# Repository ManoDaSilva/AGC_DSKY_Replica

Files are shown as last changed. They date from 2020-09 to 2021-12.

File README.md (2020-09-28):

# AGC_DSKY_Replica
Mechanically accurate Apollo DSKY replica.

This project is based off the 3D models I re-created from the original MIT Instrumentation Labs drawings (those models can be found on [VirtualAGC's GitHub](https://github.com/virtualagc/virtualagc/tree/mechanical/3D-models)). 
In order to 3D print them, I slightly modified them (widened some holes for brass inserts, keyboard, etc).

A Raspberry Pi running VirtualAGC is doing the grunt work, the display is a simple LCD and the status lights are LEDs. 

More on the [Hackaday.io project page](https://hackaday.io/project/174524).

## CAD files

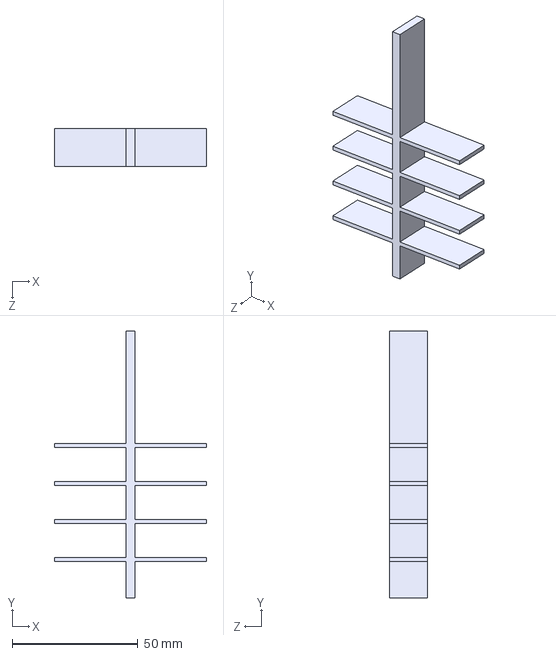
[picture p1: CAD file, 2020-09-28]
3D Models/Led_splitter.stp
60.5 x 106.1 x 15.0 mm

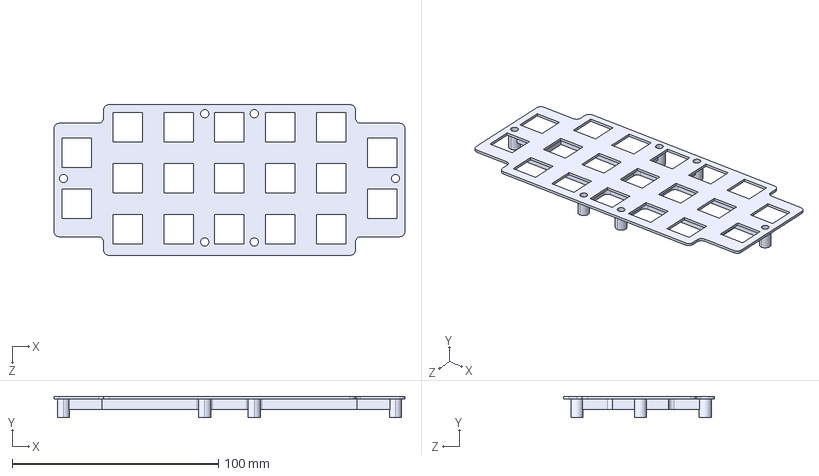
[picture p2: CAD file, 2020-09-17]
3D Models/Keyboard Mk1/cherrysupport-nopcb.stp
170.0 x 10.3 x 73.0 mm

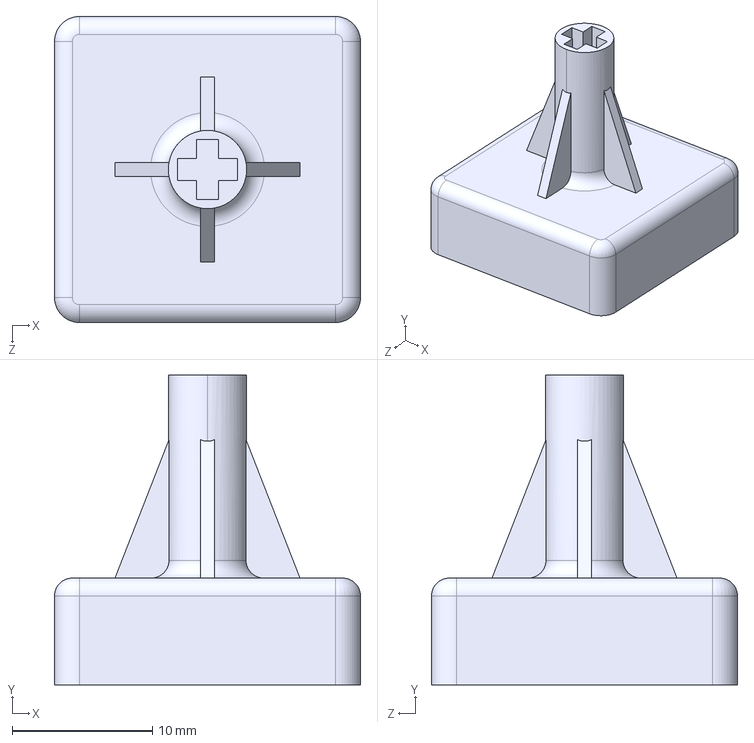
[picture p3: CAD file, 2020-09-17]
3D Models/Keyboard Mk1/keyboard case.stp
21.8 x 22.1 x 21.8 mm

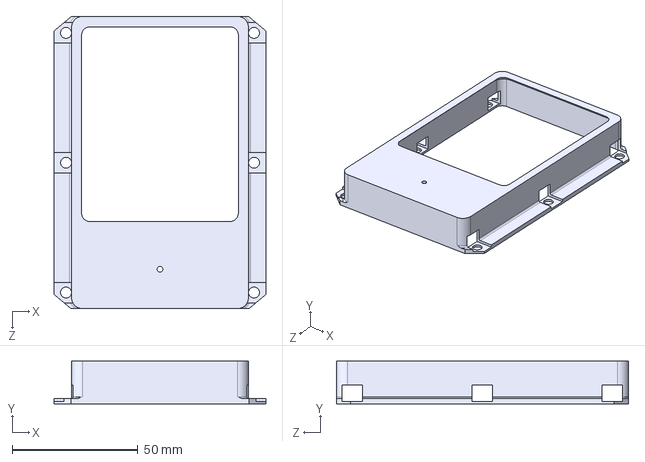
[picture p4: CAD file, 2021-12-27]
3D Models/2004699A-000.STEP
84.2 x 17.0 x 116.1 mm

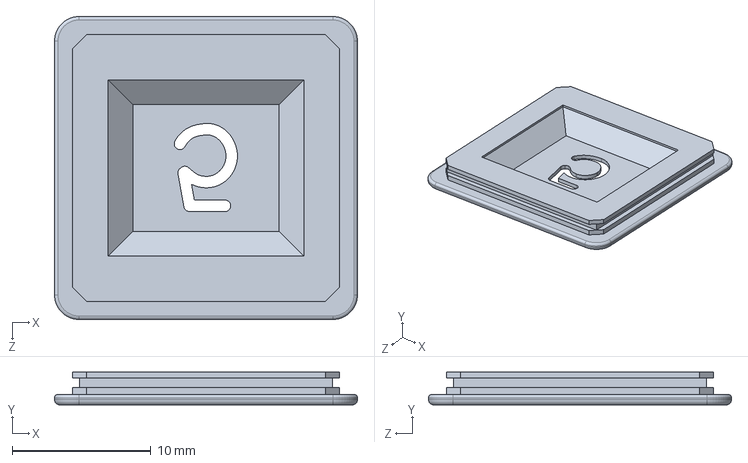
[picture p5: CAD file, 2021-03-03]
3D Models/Keyboard Mk1/1005022-015.STEP
21.8 x 2.36 x 21.8 mm

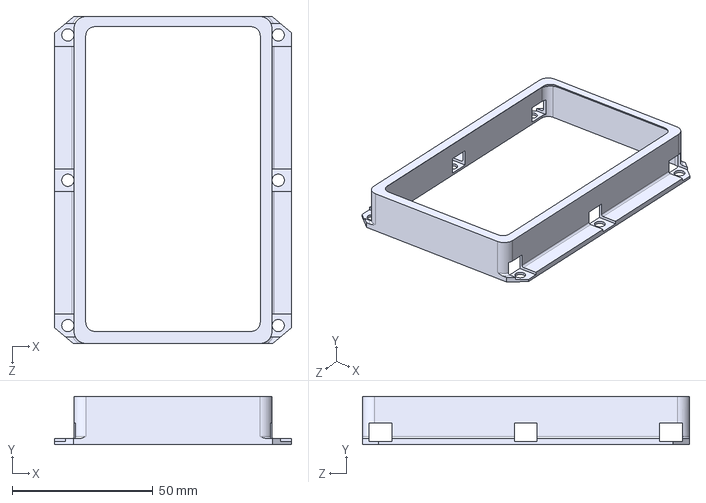
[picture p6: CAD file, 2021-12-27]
3D Models/2004699A-001.STEP
84.2 x 17.0 x 116.1 mm

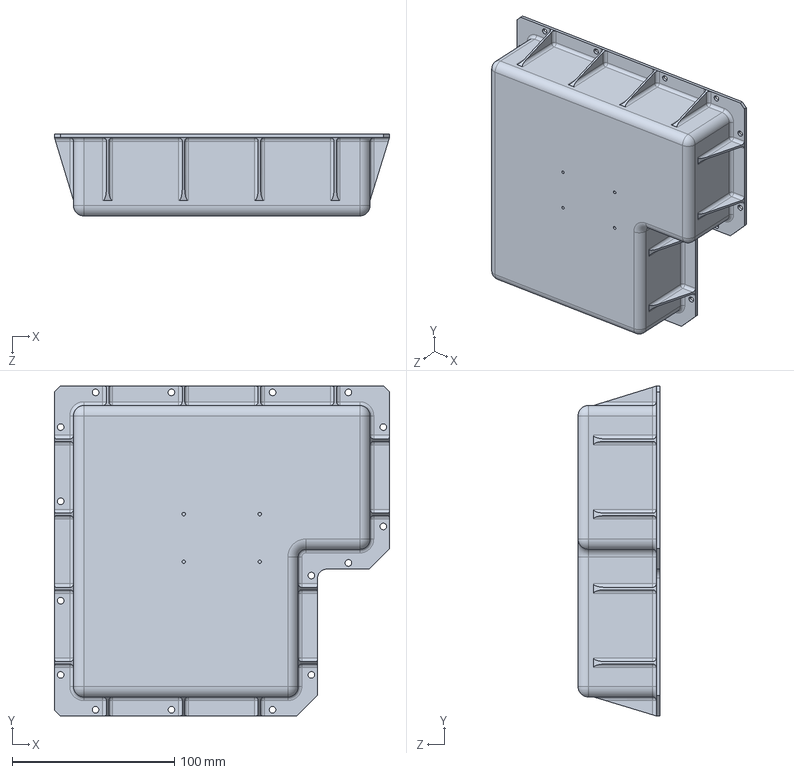
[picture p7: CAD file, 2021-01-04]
3D Models/2004900A.stp
206.3 x 203.2 x 50.4 mm

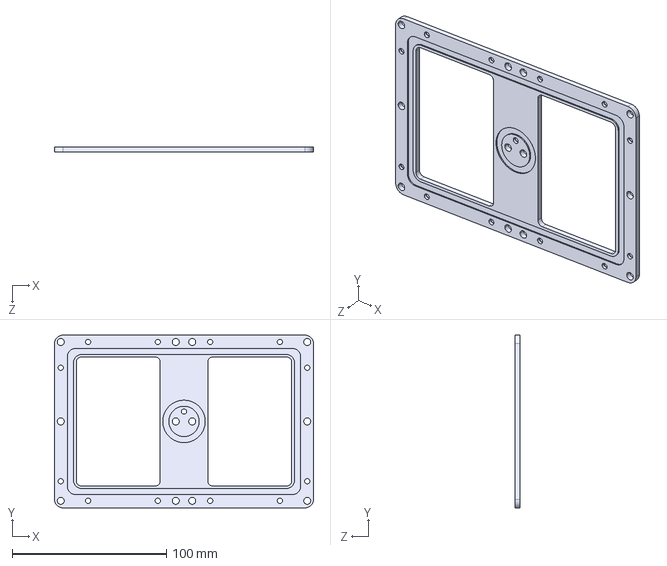
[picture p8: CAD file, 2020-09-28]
3D Models/1006315A.stp
168.1 x 112.1 x 3.18 mm

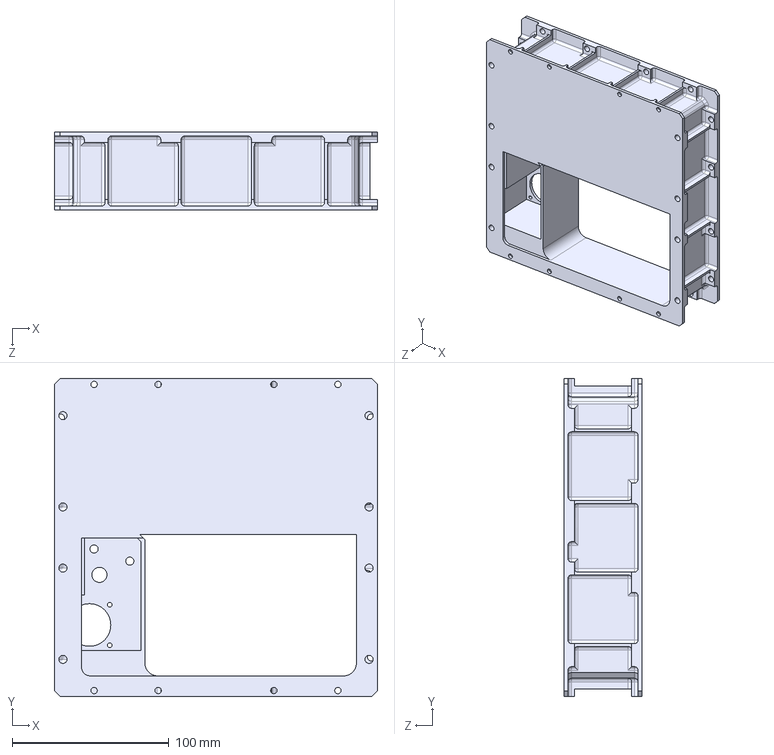
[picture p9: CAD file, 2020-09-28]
3D Models/2004705A_modfor3Dprint.stp
206.3 x 203.2 x 49.8 mm

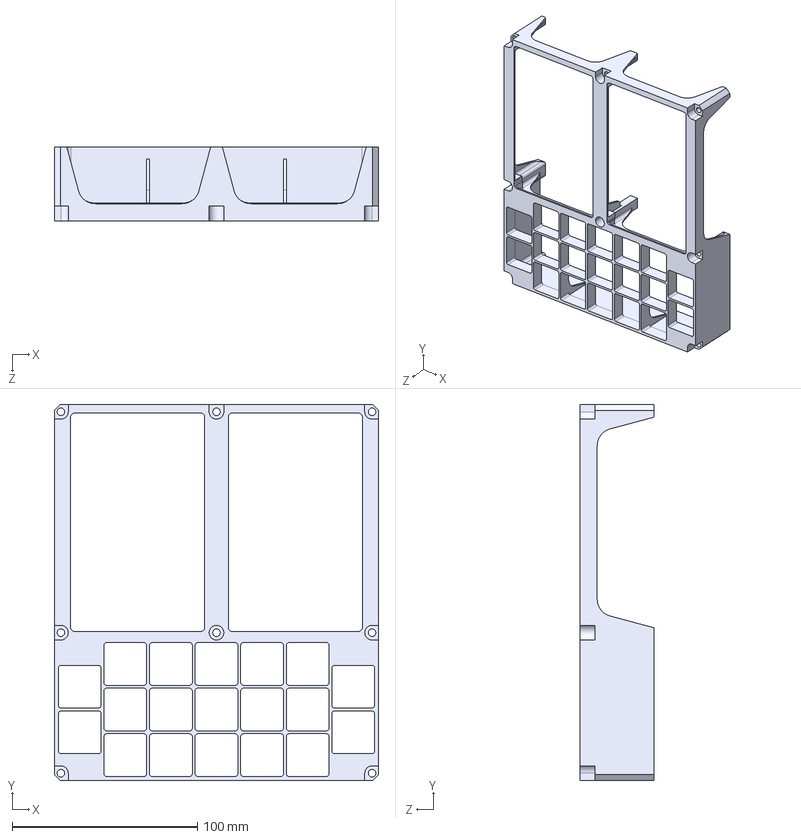
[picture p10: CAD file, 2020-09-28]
3D Models/2004739A-021-ModFor3DPrint.stp
175.3 x 203.2 x 39.9 mm

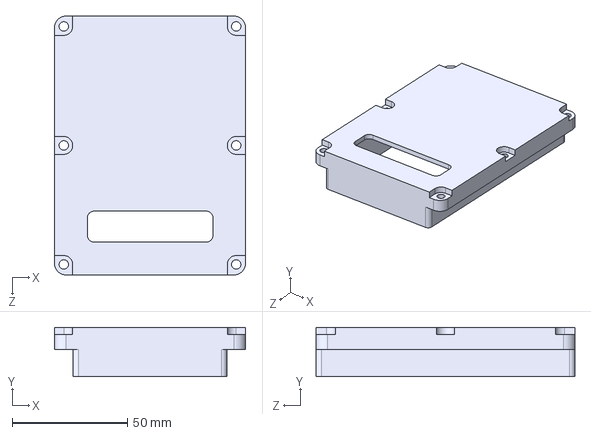
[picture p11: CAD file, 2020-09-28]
3D Models/1006387D-ModFor3DPrint.stp
82.8 x 21.3 x 112.2 mm

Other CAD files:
3D Models/Keyboard Mk1/1005022-007.STEP
3D Models/Keyboard Mk1/1005022-003.STEP
3D Models/Keyboard Mk1/1005022-018.STEP
3D Models/Keyboard Mk1/1005022-013.STEP
3D Models/Keyboard Mk1/1005022-008.STEP
3D Models/Keyboard Mk1/1005022-001.STEP
3D Models/Keyboard Mk1/1005022-006.STEP
3D Models/1006315G-ModFor3DPrint.stp
3D Models/1006315GCover-ModFor3DPrintNextIon.stp
3D Models/1006387DCover-ModFor3DPrint.stp
3D Models/2004919E-ModFor3DPrint.stp
3D Models/2004968E-ModFor3DPrint.stp
3D Models/Keyboard Mk1/1005022-002.STEP
3D Models/Keyboard Mk1/1005022-004.STEP
3D Models/Keyboard Mk1/1005022-005.STEP
3D Models/Keyboard Mk1/1005022-009.STEP
3D Models/Keyboard Mk1/1005022-010.STEP
3D Models/Keyboard Mk1/1005022-011.STEP
3D Models/Keyboard Mk1/1005022-012.STEP
3D Models/Keyboard Mk1/1005022-014.STEP
3D Models/Keyboard Mk1/1005022-016.STEP
3D Models/Keyboard Mk1/1005022-017.STEP
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

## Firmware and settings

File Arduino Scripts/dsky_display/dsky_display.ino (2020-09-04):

/*receives serial data.

  INPUT
  Serial String with the following structure:
  -Position 0: UPLINK
  -Position 1: ATT
  -Position 2: STBY
  -Position 3: KEY
  -Position 4: ERR
  -Position 5: TEMP
  -Position 6: GIMBAL
  -Position 7: PROG
  -Position 8: RESTART
  -Position 9: TRACKER
  -Position 10: ALT
  -Position 11: VEL
  -Position 12: PLACEHOLDER LED
  -Position 13: COMP ACTY
  -Position 14 and 15: PROGRAM Value
  -Position 16 and 17: VERB Value
  -Position 18 and 19: NOUN Value
  -Position 20, 21, 22, 23, 24, 25: R1 Value
  -Position 26, 27, 28, 29, 30, 31: R2 Value
  -Position 32, 33, 34, 35, 36, 37: R3 Value


*/

#define UPLINK 12
#define ATT 11
#define STBY 10
#define KEY 9
#define ERR 8

#define TEMP 14
#define GIMBAL 15
#define PROG 16
#define RESTART 17
#define TRACKER 18


const byte numChars = 40;
char receivedChars[numChars];   // an array to store the received data
boolean newData = false;
#include <SoftwareSerial.h>
#include <Nextion.h>

String oldprog;
String oldverb;
String oldnoun;
String prog;
String verb;
String noun;
String oldr1;
String oldr2;
String oldr3;
String r1;
String r2;
String r3;
int compactystatus;
int oldcompactystatus;


SoftwareSerial nextion(2, 3);// Nextion TX to pin 2 and RX to pin 3 of Arduino

Nextion myNextion(nextion, 9600); //create a Nextion object named myNextion using the nextion serial port @ 9600bps


void setup() {
  // put your setup code here, to run once:
  pinMode(UPLINK, OUTPUT);
  pinMode(ATT, OUTPUT);
  pinMode(STBY, OUTPUT);
  pinMode(KEY, OUTPUT);
  pinMode(ERR, OUTPUT);
  pinMode(TEMP, OUTPUT);
  pinMode(GIMBAL, OUTPUT);
  pinMode(PROG, OUTPUT);
  pinMode(RESTART, OUTPUT);
  pinMode(TRACKER, OUTPUT);

  Serial.begin(115200);
  myNextion.init();

}

void loop() {
  // put your main code here, to run repeatedly:

  recvWithEndMarker();
  processNewData();




}


void recvWithEndMarker() {
  static byte ndx = 0;
  char endMarker = '\n';
  char rc;

  while (Serial.available() > 0 && newData == false) {
    rc = Serial.read();

    if (rc != endMarker) {
      receivedChars[ndx] = rc;
      ndx++;
      if (ndx >= numChars) {
        ndx = numChars - 1;
      }
    }
    else {
      receivedChars[ndx] = '\0'; // terminate the string
      ndx = 0;
      newData = true;
    }
  }
}

void processNewData() {
  if (newData == true) {
    //Serial.println(receivedChars);
    writeToLED();
    writeToDisplay();
    newData = false;
  }
}

void writeToLED() {
  setLEDStatus(UPLINK, (int)receivedChars[0] - 48);
  setLEDStatus(ATT, (int)receivedChars[1] - 48);
  setLEDStatus(STBY, (int)receivedChars[2] - 48);
  setLEDStatus(KEY, (int)receivedChars[3] - 48);
  setLEDStatus(ERR, (int)receivedChars[4] - 48);
  setLEDStatus(TEMP, (int)receivedChars[5] - 48);
  setLEDStatus(GIMBAL, (int)receivedChars[6] - 48);
  setLEDStatus(PROG, (int)receivedChars[7] - 48);
  setLEDStatus(RESTART, (int)receivedChars[8] - 48);
  setLEDStatus(TRACKER, (int)receivedChars[9] - 48);
}

void writeToDisplay() {
  prog = formatChar(receivedChars[14]) + formatChar(receivedChars[15]);
  verb = formatChar(receivedChars[16]) + formatChar(receivedChars[17]);
  noun = formatChar(receivedChars[18]) + formatChar(receivedChars[19]);
  r1 = formatChar(receivedChars[20]) + formatChar(receivedChars[21]) + formatChar(receivedChars[22]) + formatChar(receivedChars[23]) + formatChar(receivedChars[24]) + formatChar(receivedChars[25]);
  r2 = formatChar(receivedChars[26]) + formatChar(receivedChars[27]) + formatChar(receivedChars[28]) + formatChar(receivedChars[29]) + formatChar(receivedChars[30]) + formatChar(receivedChars[31]);
  r3 = formatChar(receivedChars[32]) + formatChar(receivedChars[33]) + formatChar(receivedChars[34]) + formatChar(receivedChars[35]) + formatChar(receivedChars[36]) + formatChar(receivedChars[37]);
  if (prog != oldprog) {
    myNextion.setComponentText("p", prog);
    oldprog = prog;
  }
  if (verb != oldverb) {
    myNextion.setComponentText("v", verb);
    oldverb = verb;
  }
  if (noun != oldnoun) {
    myNextion.setComponentText("n", noun);
    oldnoun = noun;
  }
  if (r1 != oldr1) {
    myNextion.setComponentText("r1", r1);
    oldr1 = r1;
  }
  if (r2 != oldr2) {
    myNextion.setComponentText("r2", r2);
    oldr2 = r2;
  }
  if (r3 != oldr3) {
    myNextion.setComponentText("r3", r3);
    oldr3 = r3;
  }
  compactystatus = (int)receivedChars[13] - 48;
  if (compactystatus != oldcompactystatus) {
    setCompActyStatus((int)receivedChars[13] - 48);
    oldcompactystatus = compactystatus;
  }


}


void setLEDStatus(int pin, int state) {
  //Serial.println(pin);
  //Serial.println(state);
  switch (state) {
    case 0: //TURN OFF
      digitalWrite(pin, LOW);
      break;
    case 1: //TURN ON
      digitalWrite(pin, HIGH);
      break;
    case 2: //BLINK
      digitalWrite(pin, HIGH);
      //PLZ IMPLEMENT ME!
      break;
    case 3: //IGNORE
      //DO NOTHING HERE
      break;
  }
}

void setCompActyStatus(int state) {
  switch (state) {
    case 0: //TURN OFF
      myNextion.setComponentTextColor("t6", false);
      break;
    case 1: //TURN ON
      myNextion.setComponentTextColor("t6", true);
      break;
    case 3: //IGNORE
      //DO NOTHING HERE
      break;
  }
}

String formatChar(char input) {
  String output;
  switch (input) {
    case 32:
      output = " ";
      break;
    case 43:
      output = "+";
      break;
    case 45:
      output = "-";
      break;
    default:
      output = String((int)input - 48);
      break;
  }
  return output;
}

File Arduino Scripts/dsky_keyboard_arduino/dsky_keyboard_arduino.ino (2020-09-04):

/* @file CustomKeypad.pde
  || @version 1.0
  || @author Alexander Brevig
  || @contact alexanderbrevig@gmail.com
  ||
  || @description
  || | Demonstrates changing the keypad size and key values.
  || #
*/
#include <Keypad.h>
#include "Keyboard.h"

const byte ROWS = 5; //four rows
const byte COLS = 4; //four columns
//define the cymbols on the buttons of the keypads
//DONE: Converted numbers and symbols to ascii codes
//222 '\336' Keypad -
//223 '\337' Keypad +
//224 '\340' Keypad ENTER
//225 '\341' Keypad 1 and End
//226 '\342' Keypad 2 and Down Arrow
//227 '\343' Keypad 3 and PageDn
//228 '\344' Keypad 4 and Left Arrow
//229 '\345' Keypad 5
//230 '\346' Keypad 6 and Right Arrow
//231 '\347' Keypad 7 and Home
//232 '\350' Keypad 8 and Up Arrow
//233 '\351' Keypad 9 and PageUp
//234 '\352' Keypad 0 and Insert
char hexaKeys[ROWS][COLS] = {
  {'C', 'P', 'K', 'E'},
  {'\351', '\346', '\343', 'R'},
  {'\350', '\345', '\342', 'E'},
  {'\347', '\344', '\341', 'N'},
  {'\337', '\336', '\352', 'V'}
};
byte rowPins[ROWS] = {6, 5, 4, 3, 2}; //connect to the row pinouts of the keypad
byte colPins[COLS] = {10, 9, 8, 7}; //connect to the column pinouts of the keypad

//initialize an instance of class NewKeypad
Keypad customKeypad = Keypad( makeKeymap(hexaKeys), rowPins, colPins, ROWS, COLS);

void setup() {
  Serial.begin(9600);
  Keyboard.begin();
}

void loop() {
  char customKey = customKeypad.getKey();

  if (customKey) {
    Serial.println(customKey);
    Keyboard.print(customKey);
  }
}

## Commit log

2020-09-17 Added custom 3D printed parts
    [2004968E-ModFor3DPrint.STL, 2004968E-ModFor3DPrint.stp, cherrysupport-nopcb.STL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]
2020-09-28 Added more STL and STP files for Mk1
    [1006315A.STL, 1006315A.stp, 1006315G-ModFor3DPrint.STL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]
2021-01-04 Added back case
    [2004900A.STL, 2004900A.stp]
2021-03-03 Added Keycaps, moved some files
    [1005022-001.STEP, 1005022-001.STL, 1005022-002.STEP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]
2021-12-27 Added some more files I forgot
    How did I miss those?
    [2004699A-000.STEP, 2004699A-000.STL, 2004699A-001.STEP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]
